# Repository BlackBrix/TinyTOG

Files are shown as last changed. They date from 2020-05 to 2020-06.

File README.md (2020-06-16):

since ATtiny15 MCU is not available anymore, please see the updated project with ATtiny25 in this subfolder here (German):  
[https://github.com/BlackBrix/TinyTOG/tree/master/TinyTOG_NEW_with_ATtiny25#tinytog](https://github.com/BlackBrix/TinyTOG/tree/master/TinyTOG_NEW_with_ATtiny25#tinytog) (German)  
* * *

Oil Sensor Emulation - TinyTOG
==============================

Many Audi type 89, B4 and A4 (B5) enthusiasts want to replace their instrument cluster by a more modern one from an A4 (B5) or A6 (C5). Some just want a more modern design. Others want to equip their car with an orignal Audi radio navigation system, called RNS-D.  
The RNS-D was offered by Audi in two major versions. The first one from about 1997 to 1999 communicates with the instrument cluster via a three-wire-bus the latter one from 2000 to about 2003 uses a CAN bus. So different versions of the RNS-D need different versions of the instrument clusters. Mechanically this makes no difference. From the electronics point of view the CAN bus makes a big difference. But this is another story.  
Along with the CAN bus comes another problem to deal with. These CAN instrument clusters do not have a oil temperature gauge powered by a normal sensor. They communicate with an totally different, intelligent sensor called TOG, made by German manufacturer Hella.  
Retrofitting the TOG is not an option, because Audi invented new oil sumps together with the TOG.  
  
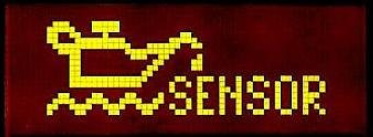
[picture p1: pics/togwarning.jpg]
TOG Warning
  
  
A missing TOG brings up two problems. At first the oil temperature gauge does not work and second the instrument clusters displays a permanent warning message concerning a malfunctioning TOG. This warning cannot be disabled by altering the coding of the instrument clusters. So a different approach had to be taken: TinyTOG.  
  
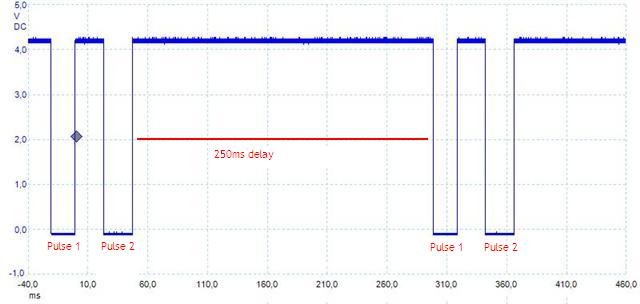
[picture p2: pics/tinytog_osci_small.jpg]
Oscilloscope
  
  
The TOG by Hella uses a simple pulse sequence with the time between two pulses and the length of the pulses representing oil temperature and oil condition/quality. As TinyTOG focuses on engines before 2000 (without long life service) only the coding of the oil temperature was analyzed. It turned out that time between the first and the second pulse together with the length of the second pulse represent the oil temperature. The first pulse is constantly 20ms long. The delay between two cycles must be at least 250ms long.  
  
  Temperature | Time between pulses | Length of pulse 2
  ------------- | ------------- | -------------
41°C | 23.0ms | 24.0ms
60°C | 26.3ms | 27.0ms
65°C | 27.0ms | 27.8ms
70°C | 28.0ms | 28.3ms
75°C | 28.5ms | 29.3ms
80°C | 29.3ms | 30.0ms
85°C | 30.3ms | 30.8ms
90°C | 31.0ms | 31.5ms
95°C | 31.8ms | 32.5ms
100°C | 32.5ms | 33.3ms
105°C | 33.3ms | 34.0ms
110°C | 34.0ms | 35.0ms
115°C | 35.0ms | 35.8ms
120°C | 35.8ms | 36.8ms
125°C | 36.8ms | 37.5ms
130°C | 37.5ms | 38.3ms
135°C | 38.3ms | 39.3ms
140°C | 39.3ms | 40.0ms
145°C | 40.0ms | 40.8ms
150°C | 41.0ms | 41.8ms
155°C | 41.8ms | 42.8ms
160°C | 42.8ms | 43.5ms
165°C | 43.5ms | 44.5ms
170°C | 44.5ms | 45.3ms

In the 1990s almost all Audis equipped with an oil temperature gauge use an oil temperature sensor, part numer 049 919 6563.  
  
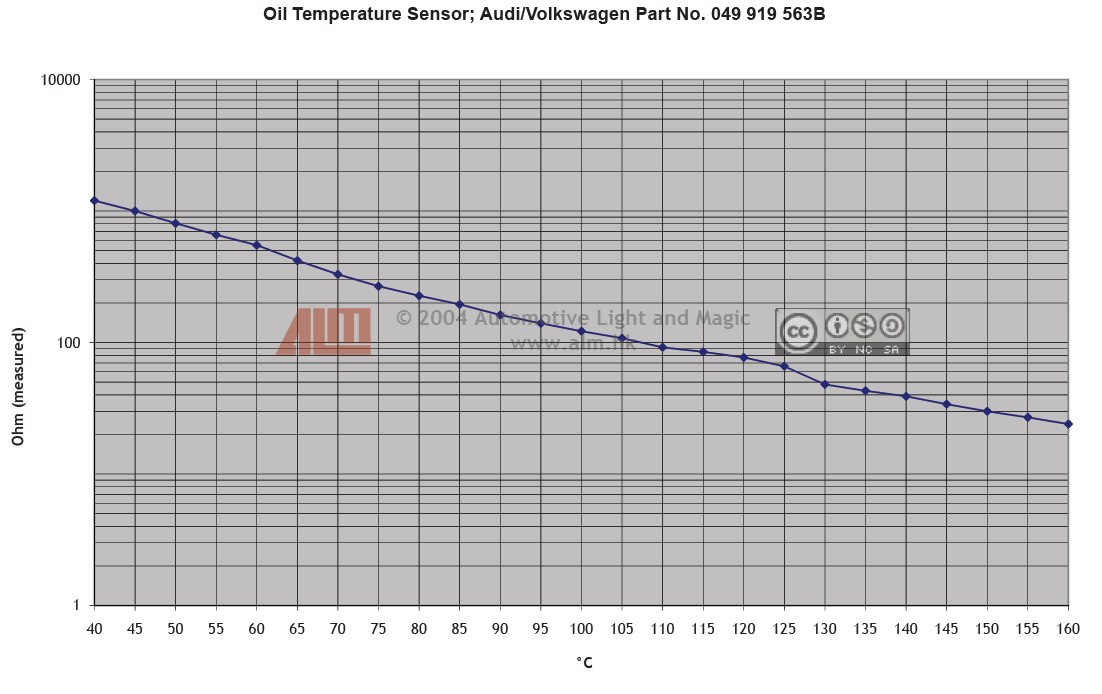
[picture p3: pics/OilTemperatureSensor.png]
Oil Temperature Sensor
  
  
The analog voltage signal from this sensor has to be translated into the above pulse coded signal understood by the instrument cluster. This is done by Atmel's ATTiny15 with its internal 8Bit-ADC. As the oil temperature is a rather imprecise one a stepping of 5K gives enough precision. The gauge's scale begin's at 60°C. So temperature below that don't have to be measured.  
  
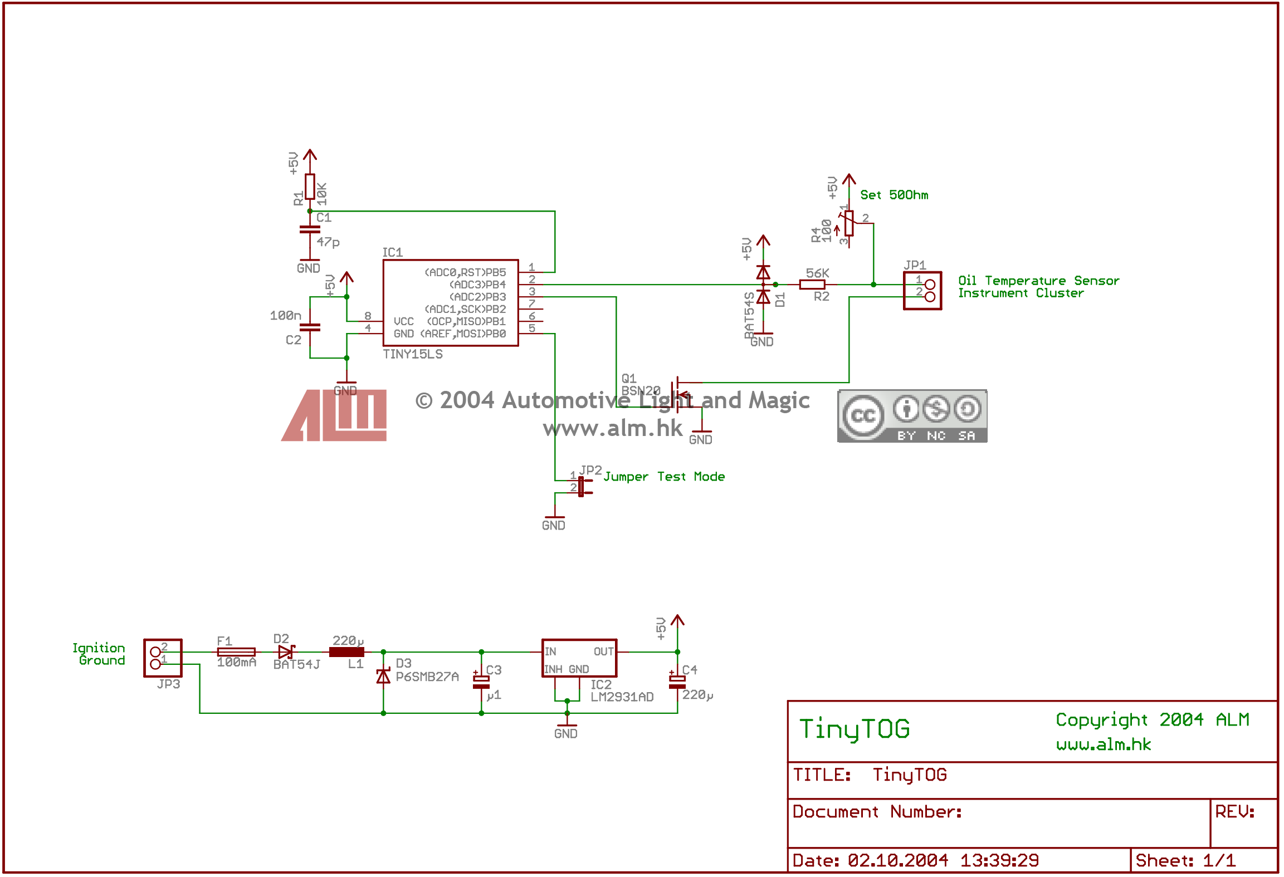
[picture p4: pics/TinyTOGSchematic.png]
TinyTOG Schematic
  
  
TinyTOG needs only be connected to ignition, the instrument cluster and the oil temperature sensor. A jumper is provided to bring up a test mode. Normally this jumper should be left open. By shortening to ground and switching on ignition the fuel gauge should travel from 60°C to full scale and reverse as long as ignition stays high.  
The oil temperature sensor together with an 100Ohm potentiometer form a voltage divider. At first time startup the potentiometer should be tuned to about 50Ohm. Minor adjustments could be made by tuning the potentiometer, but in most cases this is not necessary.  

Downloads
---------

  Content       | License
  ------------- | -------------
  [Schematic and Demo Board](https://github.com/BlackBrix/TinyTOG/tree/master/hardware)  | Creative Commons License (https://creativecommons.org/licenses/by-nc-sa/3.0/hk/)
  [Source code](https://github.com/BlackBrix/TinyTOG/raw/master/firmware/TinyTOG.asm)  | Creative Commons License (https://www.gnu.org/licenses/old-licenses/gpl-2.0.en.html)
  [Intel HEX File](https://github.com/BlackBrix/TinyTOG/raw/master/firmware/TinyTOG.hex)³  |  Creative Commons License (https://www.gnu.org/licenses/old-licenses/gpl-2.0.en.html)
  
³(Internal oscillator calibration set to 0x78)

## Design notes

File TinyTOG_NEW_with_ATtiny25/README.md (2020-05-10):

Audi S4 B5 - Kombiinstrument-Umbau von Vor-Facelift zu Facelift
===============================================================

Der Umbau eines Kombiinstruments (KIs) ist eigentlich keine grosse Sache, wird aber, wenn man ein KI eines anderen Fahrzeugtyps oder eines anderen Modelljahrs des gleichen Fahrzeugstyps umbauen möchte, eventuell wesentlich schwieriger. Einer dieser schwierigen Fälle wird hier beschrieben: Tausch eines KI von einem Audi S4 B5 Modelljahr 1999, nachfolgend als Vor-Facelift bezeichnet, mit einem KI aus einem Audi S4 B5 Modelljahr 2000, nachfolgend als Facelift bezeichnet.

Das KI des Vor-Facelift, nachfolgend als altes KI bezeichnet,

*   mit der Teilenummer 8D0 919 881 L
    
*   ist von VDO,
    
*   hat eine Wegfahrsperre der Generation 2 (WFS 2) und
    
*   eine analoge Uhr.

Das KI des Facelift, nachfolgend als neues KI bezeichnet,

*   mit der Teilenummer 8D0 920 932 JX
    
*   ist ebenfalls von VDO,
    
*   unterstützt CAN-Bus,
    
*   hat ebenfalls eine WFS 2,
    
*   eine digitale Uhr mit Datumsanzeige und
    
*   eine Anschlussmöglichkeit für eine Funkuhr.

Das X am Ende der Teilenummer sagt aus, dass es sich um ein Austauschteil handelt.

Adaption
--------

### Mehrfachstecker

Die Anschlussbuchsen sowie dessen Belegungen unterscheiden sich bei den beiden KIen. Das alte KI hat einen 32-poligen, blauen Anschluss, einen 32-poligen. grünen Anschluss und einen 20-poligen, roten Anschluss. Das neue KI hat ebenfalls den blauen und grünen Anschluss, aber anstelle eines roten Anschlusses einen 32-poligen, grauen Anschluss.

**Übersicht der Belegungen von altem KI zu neuem KI**

Die nachfolgende Tabelle zeigt, wie das neue KI belegt werden muss. Eine Spalte beinhaltet alle Belegungen eines bestimmten Steckers des alten KI und die passende Belegung beim neuen KI. Eine Belegung besteht aus dem Pin und der Farbe des Steckers. In der Spalte auf der linken Seite steht die ursprüngliche Belegung beim alten KI, auf der rechten Seite die passende Belegung bei dem neuen KI.

blauer Stecker | grüner Stecker | roter Stecker
------------- | ------------- | -------------
1 blau → 1 blau | 2 grün → 2 grün | 1 rot → 25 blau 
2 blau → 7 grün | 4 grün → frei | 5 rot → 29 grün 
3 blau → 3 blau | 5 grün → 5 grün | 6 rot → 31 grün 
5 blau → 5 blau | 6 grün → 6 grün | 9 rot → 15 grau 
6 blau → 10 grün | 7 grün → 2 blau | 10 rot → frei 
7 blau → 7 blau | 10 grün → 6 blau | 11 rot → 19 grau 
8 blau → 8 blau | 11 grün → 11 grün | 12 rot → 12 grau 
9 blau → 9 blau | 12 grün → 12 blau | 13 rot → 13 grau 
10 blau → 10 blau | 13 grün → 13 grün | 14 rot → 17 grau 
11 blau → 11 blau | 14 grün → 13 blau | 15 rot → 11 grau 
12 blau → 12 grün | 15 grün → frei | 16 rot → 16 grau 
13 blau → 14 grün | 17 grün → 17 grün | 17 rot → frei 
14 blau → 14 blau | 21 grün → 15 grün | 18 rot → 18 grau 
15 blau → 15 blau | 29 grün → frei | 19 rot → 14 grau 
16 blau → 16 blau | 30 grün → 31 blau |  
17 blau → 17 blau |  |  
18 blau → 18 blau |  |  
19 blau → 21 grün |  |  
20 blau → 20 blau |  |  
21 blau → 21 blau |  |  
22 blau → 22 blau |  |  
23 blau → 23 blau |  |  
24 blau → 24 blau |  |  
25 blau → 28 grün |  |  
26 blau → 26 blau |  |  
27 blau → 27 blau |  |  
28 blau → 28 blau |  |  
29 blau → 29 blau |  |  
30 blau → 30 blau |  |  
31 blau → 27 grün |  |  
32 blau → 32 blau |  |  

*   21 grün vom alten KI ist das Signal des normalen Ölsensors und geht über den TinyTOG zu 15 grün des neuen KIs, um ein TOG-Signal zu emulieren

**Benötigte Teile**

Anz. | Bezeichnung | VAG-Teilenummer
----------| --------- | ---------
1x | Stecker grün | 8L0 972 977 C
1x | Stecker blau | 8L0 972 977 D
1x | Stecker grau | 8L0 972 977 G

Die Kabel habe ich aus ein paar Flachbandkabeln, wie sie bei Computern (IDE-/SCSI\-Kabel) verwendet werden, herausgetrennt.

**Abbildung der Rückseite des neuen KIs**

Bei der Belegung des neuen KIs habe ich keine Änderung an den Steckern am Kabelbaum des Fahrzeugs durchgeführt. Damit ist gewährleistet, dass ich jederzeit ein zu dem Modelljahr passendes KI einbauen kann, um den Originalzustand wiederherzustellen.

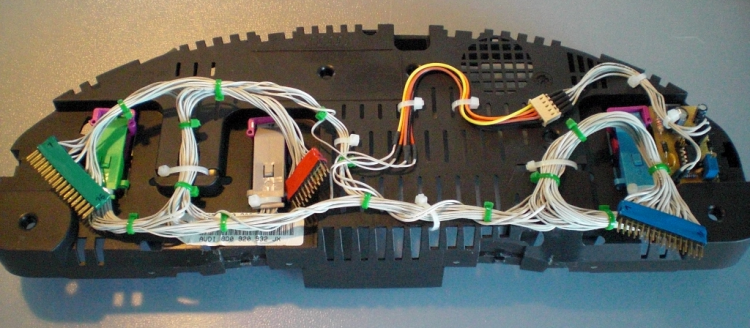
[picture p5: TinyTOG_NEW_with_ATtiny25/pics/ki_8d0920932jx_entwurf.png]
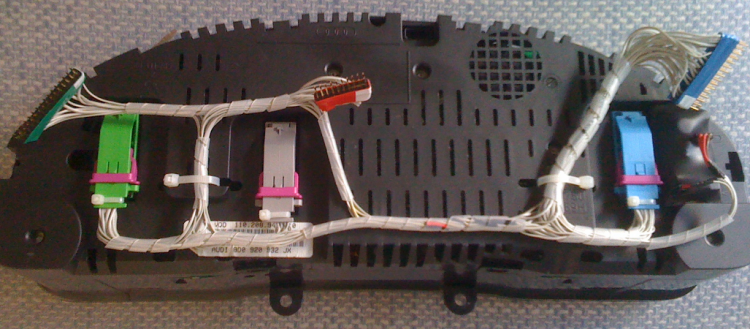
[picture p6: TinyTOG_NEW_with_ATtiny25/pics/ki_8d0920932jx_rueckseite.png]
   

Bei der Belegung ist auf passende Kabellängen zu achten, damit keine Zugbelastungen einzelner Kabel auftreten.

### Temperatur- und Ölstandgeber

Das neue KI hat ein paar mehr Anzeige-Möglichkeiten als das alte KI, sofern entsprechende Sensoren im Fahrzeug verbaut sind, und benötigt einen Temperatur- und Ölstandgeber (TOG), welcher beim Facelift im Zuge der variablen Serviceintervalle (Longlife) eingeführt wurde. Dieser Sensor sitzt beim Facelift auf der Unterseite der Ölwanne, beim Vorface-Lift gibt es diesen Sensor nicht.

Das neue KI wird immer eine Ölstandswarnmeldung anzeigen, wenn es kein plausibles Signal von einem TOG bekommt.



### TinyTOG

Das Signal vom TOG wird mit einer Schaltung, dem TinyTOG von [Automotive Light and Magic (ALM)](http://www.alm.hk/ "http://www.alm.hk"), emuliert. Damit kann der alte Ölsensor (049 919 563 B) weiterverwendet werden und das neue KI zeigt nicht dauerhaft eine Ölstandswarnmeldung an.

Das Herzstück ist ein AVR-Microcontroller, welcher mit dem TinyTOG-Programm die Signale des Ölsensors in TOG-Signale übersetzt. Der Ölsensor gibt die Öltemperatur durch Änderung seines Widerstands an. Der TOG erzeugt wiederkehrend zwei Pulse und eine Pulspause. Die Zeit zwischen den zwei Pulsen und die Länge des zweiten Pulses beschreibt die Öltemperatur.

Der TinyTOG wandelt also den Widerstandswert des Ölsensors in entsprechende Pulse, die ein TOG geben würde, um. Der erste Puls (high = VCC = 5V) ist immer 20 ms lang, die Pause (low = GND = 0V) zwischen erstem und zweiten Puls hat eine Dauer von 23 bis ca. 44 ms, der zweite Puls (high) ist zwischen 24 und 45 ms lang. Das Intervall (low) zwischen den Signalen berägt 250 ms.

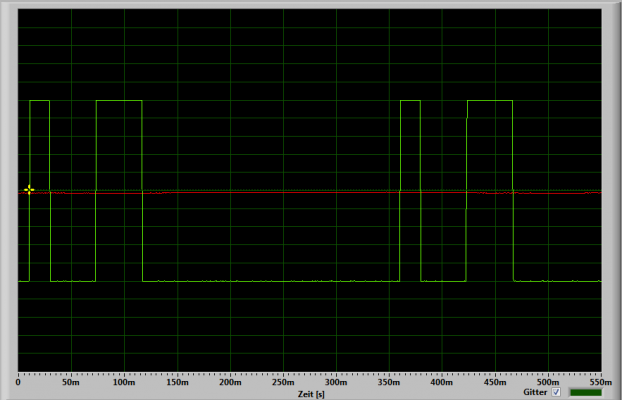
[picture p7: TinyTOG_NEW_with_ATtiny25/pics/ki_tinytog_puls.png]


Folgende Werte ergeben sich für den Ölsensor (049 919 563 B) zur Messung des Widerstandes und damit der Öltemperatur über einen Spannungsteiler mit einem ATtiny25:

*   50 Ohm-Spannungsteiler
    
*   5 V Referenz- und Versorgungsspannung
    
*   10 Bit-Analog-/Digital-Konverter (ADC)
    
Öltemperatur | Ölsensor | U-variabel | ADC | ADCH | 1\. Puls | Pulspause | 2\. Puls
------------ | -------- | ---------- | -------- | -------- | -------- | -------- | -------
**\[°C\]** | **\[Ohm\]** | **\[V\]** | **(10 Bit)** | **(8 Bit)** | **\[ms\]** | **\[ms\]** | **\[ms\]**
41 | 1200 | 4,80 | 983 | 246 | 20,00 | 23,00 | 24,00  
60 | 550 | 4,58 | 939 | 235 | 20,00 | 26,25 | 27,00  
65 | 420 | 4,47 | 915 | 229 | 20,00 | 27,00 | 27,75  
70 | 330 | 4,34 | 889 | 222 | 20,00 | 28,00 | 28,25  
75 | 268 | 4,21 | 863 | 216 | 20,00 | 28,50 | 29,25  
80 | 227 | 4,10 | 839 | 210 | 20,00 | 29,25 | 30,00  
85 | 195 | 3,98 | 815 | 204 | 20,00 | 30,25 | 30,75  
90 | 162 | 3,82 | 782 | 196 | 20,00 | 31,00 | 31,50  
95 | 140 | 3,68 | 755 | 189 | 20,00 | 31,75 | 32,50  
100 | 122 | 3,55 | 726 | 182 | 20,00 | 32,50 | 33,25 
105 | 108 | 3,42 | 700 | 175 | 20,00 | 33,25 | 34,00 
110 | 92 | 3,24 | 663 | 166 | 20,00 | 34,00 | 35,00  
115 | 85 | 3,15 | 645 | 161 | 20,00 | 35,00 | 35,75  
120 | 77 | 3,03 | 621 | 155 | 20,00 | 35,75 | 36,75  
125 | 66 | 2,84 | 583 | 146 | 20,00 | 36,75 | 37,50  
130 | 48 | 2,45 | 502 | 125 | 20,00 | 37,50 | 38,25  
135 | 43 | 2,31 | 473 | 118 | 20,00 | 38,25 | 39,25  
140 | 39 | 2,19 | 449 | 112 | 20,00 | 39,25 | 40,00  
145 | 34 | 2,02 | 414 | 104 | 20,00 | 40,00 | 40,75  
150 | 30 | 1,88 | 384 | 96 | 20,00 | 41,00 | 41,75 
155 | 27 | 1,75 | 359 | 90 | 20,00 | 41,75 | 42,75  
160 | 24 | 1,62 | 332 | 83 | 20,00 | 42,75 | 43,50  
170 | 23 | 1,58 | 323 | 81 | 20,00 | 44,50 | 45,25

Die Schaltung für den TinyTOG kann ohne Probleme auf einer Lochraster-Platine aufgebaut werden.

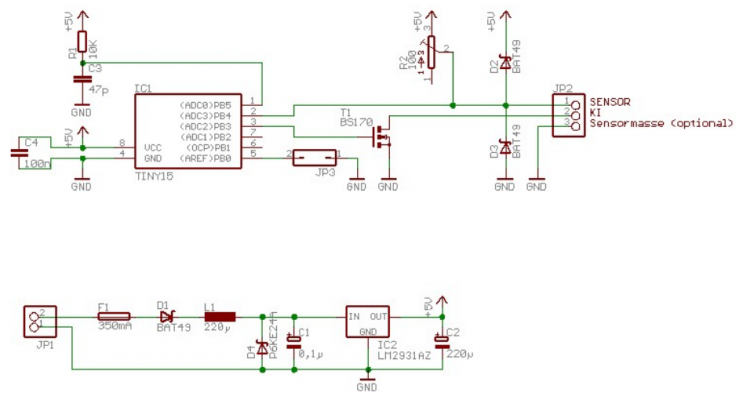
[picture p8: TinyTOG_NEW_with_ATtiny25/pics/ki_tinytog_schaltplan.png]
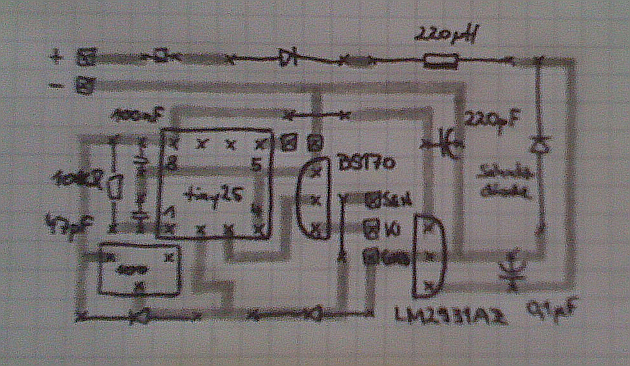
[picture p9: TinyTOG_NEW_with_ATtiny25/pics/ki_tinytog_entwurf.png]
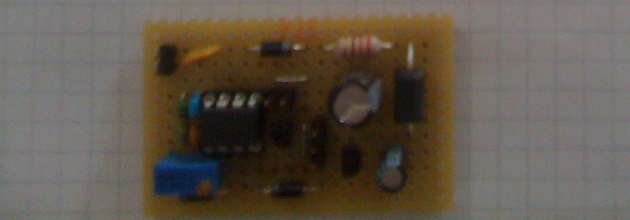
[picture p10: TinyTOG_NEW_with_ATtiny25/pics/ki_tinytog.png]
  

**Benötigte Teile**

Abk. | Anz. | Bezeichnung | Reichelt-Best.-Nr.
-------- | -------- | -------- | --------
JP1-3 | 1x  | 36-pol. Stiftleiste gerade 2,54mm | SL 1X36G 2,54
 .    | 1x | Lochrasterplatine | H25PR200
C1 | 1x | Elektrolyt 0,1µF 100V | RAD 0,1/100  
C2 | 1x | Elektrolyt 220µF 16V | RAD 220/16  
D1 | 1x | Schottky 30V 1A | SB 130  
D4 | 1x | Übersp.-Schutz-Diode | 1,5KE 24A  
F1 | 1x | Rück. Sicherung 40A 60V 3,8s | PFRA 040  
IC2 | 1x | Spannungsregler 5V | LM 2931 AZ  
L1 | 1x | Drosselspule 220µH | SMCC 220µ  
C3 | 1x | Keramik 47pF 50VDC | KERKO 47P  
C4 | 1x | Keramik 100nF 50VDC | KERKO 100N  
D2, D3 | 2x | Schottky 30V 1A | SB 130  
R1 | 1x | Metallschicht 2W 10kOhm | 2W METALL 10K  
R2 | 1x | Präzisionspoti 100Ohm | 64Y-100  
T1 | 1x | N-FET 60V 500mA | BS 170  
IC1 | 1x | Atmel AVR Tiny 25 | ATTINY 25-20 PU  
.   | 1x | IC-Sockel 8-polig | GS 8P  

Das ursprüngliche Programm für den TinyTOG ist von ALM in Assembler geschrieben worden. Die Schaltung ist von 2004 und sieht einen Atmel AVR Tiny 15 (tiny15) als Microcontroller vor, welcher aber nicht mehr hergestellt wird. Als Ersatz bietet sich ein Atmel AVR Tiny 25 (tiny25) an.

Der tiny25 kann in einen tiny15-Kompatibilitätsmodus versetzt werden, welcher den tiny25 quasi zu einem tiny15 umwandelt. Dennoch waren kleine Änderungen an dem originalen TinyTOG-Programm für den Einsatz auf einem tiny25 erforderlich.

*   das ADC Control and Status Register (ADCSR) wude von „ADCSR“ in „ADCSRA“ umbenannt
    
*   die Werte für den 10 Bit-ADC (siehe Tabelle oben) wurden angepasst

Das Programm muss auf den tiny25 übertragen werden. Für diesen Zweck kann z. B. WinAVR, welches avrdude beinhaltet, und ein einfacher IC-Programmieradapter (z. B. [SI-Prog](http://www.whoopsie.de/home/doku.php?id=topic02:item004 "topic02:item004")) verwendet werden

Nachfolgend eine Batch-Datei zum Schreiben des tiny25 mit avrdude von WinAVR mit einem SI-Prog.
~~~
@echo off
set port=com1
set prog=siprog
set mmcu=attiny25
set hexfile=TinyTOG
rem # ATtiny25-Fuses
rem 0x62 = Clock: intern 8 MHz, Prescale: 8 (default)
rem 0xE2 = Clock: intern 8 Mhz, kein Prescale
rem 0x63 = Clock: intern 1,6 MHz (tiny15)
set lfuse=0x63
avrdude.exe -p %mmcu% -P %port% -c %prog% -U lfuse:w:%lfuse%:m -U flash:w:%hexfile%.hex:a
~~~

Es können natürlich auch andere Programme (z. B. PonyProg) zum Flashen verwendet werden.

Das TinyTOG-Programm hat ein Demoprogramm integriert, um die Funktion der Schaltung zu überprüfen. Zur Aktivierung des Testprogramms werden die beiden Pins direkt neben dem Microcontroller mittels Jumper verbunden. Bei aktiviertem Testprogramm werden nacheinander Öltemperaturen in 5°C-Schritten simuliert. Beginnend bei 170°C wird ungefähr alle 80 s die simulierte Öltemperatur um 5°C geringer, bis 60°C und im nächsten Schritt 41°C erreicht sind.

Ein 100 Ohm-Präzisionspoti dient zur Feinjustierung. Da in der kleinen Öltemperaturanzeige im KI ohnehin nur eine ungefähre Anzeige möglich ist, sollte ein Wert von 50 Ohm in den meisten Fällen ausreichend genau sein.

Die Spannungsversorgung sollte über Klemme 15 (Zündungsplus) und Klemme 31 (Lastmasse) erfolgen. Beim alten und neuen KI liegt

*   Klemme 15 auf 1 blau und
    
*   Klemme 31 z. B. auf 9 blau.

Wegfahrsperre
-------------

Eine WFS ist ein verbundenes Sicherheitssystem im Fahrzeug, welche das unerlaubte Starten des Motors verhindern soll und erstreckt sich über

*   das Motorsteuergerät,
    
*   das Kombinstrument oder einer seperaten, eigenen Einheit und
    
*   den Schlüsseln.

Es ist grundsätzlich möglich ein KI mit WFS 2 oder WFS 3 in ein Fahrzeug mit WFS 2 zu verbauen. Ein KI mit WFS 2 hat nur seine 14-stellige ID gespeichert. Bei WFS 3 werden zusätzlich die 17-stellige Fahrgestellnummer, welche ebenfalls im Motorsteuergerät gespeichert ist, und Informationen zum Hersteller, Fahrzeugtyp, Modelljahr und das Herstellwerk gespeichert. Die WFS 2 wurde beim Audi S4 B5 von 1997 bis ca. 2001 verbaut.

Das neue KI muss nach dem Einbau

*   an das Motorsteuergerät angeglichen werden und
    
*   die zum Starten berechtigten Schlüssel angelernt bekommen.

Das Anlernen und Angleichen kann z. B. mit VCDS durchgeführt werden.

### Schlüssel anlernen

Voraussetzung: Das neue KI ist eingebaut und der Login-Code für das neue KI ist bekannt.

In meinem Fall hatte ich nicht den Login-Code zu dem neuen KI. Es gibt aber günstige Programme wie z. B. VAGTacho, welche über einen eigenen OBD-Stecker den Login eines KIs bis ca. Baujahr 2002 auslesen können. Ich selber habe das Programm auch genutzt, allerdings funktionierte es nur bei dem alten KI, nicht aber bei dem neuen KI. Es half nur das direkte Auslesen des EEPROMs.

Steuergerät: Schalttafeleinsatz / Kombiinstrument

*   \[Login - 11\] → fünfstelligen Login-Code des neuen KIs eingeben (z. B. für Login-Code 1234 = 01234)
    
*   \[Anpassung - 10\] → Anpassungskanal 21 auslesen
    
    *   Der gespeicherte und angezeigte Wert ist die Anzahl der alten, angelernten Schlüssel. Der Wert wird auf 0 gesetzt und gespeichert, damit die alte Schlüsselzuordnung gelöscht wird. Anschliessend wird die neue Anzahl der anzulernenden Schlüssel eingegeben und gespeichert. Nach der Speicherung ist der erste Schlüssel angelernt und die Kontrollleuchte der Wegfahrsperre im KI sollte erlischen.
        
    *   Ein neuer, anzulernender Schlüssel wird in das Zündschloss gesteckt und die Zündung einschaltet. Die Kontrollfeuchte der Wegfahrsperre schaltet sich für ca. 2 Sekunden ein und erlischt dann wieder. Der Schlüssel ist angelernt. Der Vorgang wird für alle anzulernenden Schlüssel wiederholt.

### Motorsteuergerät angleichen

Steuergerät: Schalttafeleinsatz / Kombiinstrument

*   \[Login - 11\] → fünfstelligen Login-Code des neuen KIs eingeben (z. B. für Login-Code 1234 = 01234)
    
*   \[Anpassung - 10\] → Anpassungskanal 0 auslesen und speichern, um das Motorsteuergerät mit dem KI bekannt zu machen

Login-Code und Laufleistung
---------------------------

Der 93lc86 ist ein serieller Microwire-EEPROM mit 2 kByte Speicher. Dieser EEPROM wird bei dem neuen KI zur Speicherung von u. a. Login-Code und Laufleistung genutzt, welche je nach Baujahr, Hersteller und WFS-Generation dort in irgendeiner Form abgelegt sind.

Um auf den EEPROM zugreifen zu können muss das KI geöffnet werden und mit einem IC-Programmieradapter, z. B. dem [SI-Prog](http://www.whoopsie.de/home/doku.php?id=topic02:item004 "topic02:item004") verbunden werden. Mit einem passenden Programm, z. B. PonyProg, kann dann der Inhalt des EEPROMs, der Dump, ausgelesen werden.

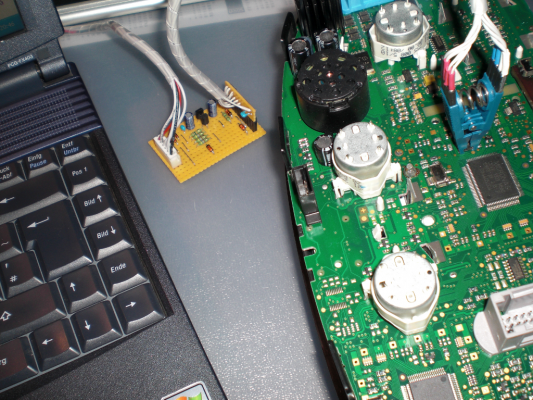
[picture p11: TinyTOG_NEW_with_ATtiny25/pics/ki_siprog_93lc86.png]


Der Dump kann als Datei gespeichert und anschließend mit einem Hex-Editor geöffnet werden. Im Hex-Editor werden 16 Bit üblicherweise hexadezimal mit vier Zeichen (jeweils von 0 bis 9, dann A bis F für dezimal 0 bis 15) angezeigt.

Der Dump ist korrekt, wenn man irgendwo im Hex-Editor eine 14-stellge WFS-ID und die Teilenummer des KIs erahnen kann.

Es gibt Programme, z. B. IMMOread by Gsmservis, welche Login-Codes aus solchen Dumps auslesen können. Für meinen Dump hat das Programm allerdings nicht funktioniert.

### Login-Code auslesen

Der Login-Code steht an der Stelle 0x7E2 dreimal hintereinander in 16 Bit Länge.



Die hexadezimale Darstellung muss lediglich in eine dezimale Darstellung gebracht werden.

*   0x000_2_ = 2 \* 16^0 = 2 \* 1 = 2
    
*   0x00_D_0 = 13 \* 16^1 = 13 \* 16 = 208
    
*   0x0_4_00 = 4 \* 16^2 = 4 \* 256 = 1024
    
*   0x_0_000 = 0 \* 16^3 = 0 \* 4096 = 0

Die dezimale Darstellung von 0x04D2 und damit der Login-Code ist 0 + 1024 + 208 + 2 = 1234.

Der Login-Code hat fast immer einen 4-stelligen Wert, muss aber in VCDS 5-stellig, hier also mit führender Null, eingegeben werden.

### Laufleistung ändern

Mit VCDS ist aus Sicherheitsgründen nur eine Anpassung eines km-Stands von unter 100 km möglich. Ein gebrauchtes KI, welches typischerweise aus einem anderen Fahrzeug ausgebaut wurde, hat in den allermeisten Fällen einen höheren km-Stand gespeichert. Eine Anpassung des km-Stands mit VCDS ist dann nicht möglich.

**Berechnung der Laufleistung**

Die Laufleistung wird hier exemplarisch ermittelt und beträgt 311.177 km. Sie wird an der Stelle 0x42 in 8 mal 16 Bit Länge im EEPROM gehalten.



Zuerst werden die beiden 16 Bit-Pakete in ihre dezimale Darstellung überführt, wobei 0xB403 fünfmal und 0xB404 dreimal vorkommt. Der Einfachheit halber braucht nur ein 16 Bit-Paket überführt werden, da das jeweils andere Paket entweder einen um den Wert 1 höheren oder niedrigeren Wert hat.

*   0x000_3_ = 3 \* 16^0 = 3 \* 1 = 3
    
*   0x00_0_0 = 0 \* 16^1 = 0 \* 16 = 0
    
*   0x0_4_00 = 4 \* 16^2 = 4 \* 256 = 1.024
    
*   0x_B_000 = 11 \* 16^3 = 11 \* 4096 = 45.056

Die hexadezimalen Werte 0xB403 bzw. 0xB404 entsprechen den dezimalen Werten 45.056 + 1.024 + 0 + 3 = 46.083 bzw. 46.083 + 1 = 46.084.

Definierte Werte:

*   a1 := dezimaler Wert des ersten 16 Bit-Pakets
    
*   a2 := dezimaler Wert des zweiten 16 Bit-Pakets
    
*   n1 := Anzahl des ersten 16 Bit-Pakets
    
*   n2 := Anzahl des zweiten 16 Bit-Pakets
    
*   x = 49
    
*   y = (n1+n2) \* 65.535 = 8 \* 65.535 = 524.280

Rechenschema:

*   a1 = 46.083
    
*   a2 = 46.084

*   b1 = n1 \* a1 = 5 \* 46.083 = 230.415
    
*   b2 = n2 \* a2 = 3 \* 46.084 = 138.252

*   b = b1 + b2 = 368.667
    
*   c = y - b = 155.613
    
*   d = c \* 2 = 311.226
    
*   e = d - 49 = 311.177

Der Wert e entspricht der Laufleistung in km.

**Anpassung der Laufleistung**

Die Änderung erfolgt im Dump, also in dem EEPROM-Abbild, welcher nach der Änderung zurück in den EEPROM geschrieben wird.

Exemplarisch wird hier die Laufleistung auf 261.039 km geändert. Dazu muss die Laufleistung wie o. a. nur in umgekehrter Reihenfolge in die hexadezimale Darstellung überführt werden.

Definierte Werte:

*   e := Wert der Laufleistung in Kilometer
    
*   n := Anzahl der darzustellenden 16 Bit-Pakete
    
*   x = 49
    
*   y = n \* 65.535 = 8 \* 65.535 = 524.280

Rechenschema:

*   e = 261.039
    
*   d = e + x = 261.088
    
*   c = d / 2 = 130.544
    
*   b = y - c = 393.736

Überführung in acht 16 Bit-Pakete:

*   a = b / n = 393.736 / 8 = 49.217

Umformung von dezimaler in hexadezimale Darstellung:

*   49.217 / 16 = 3.076 , Rest 1
    
*   3.076 / 16 = 192 , Rest 4
    
*   192 / 16 = 12 , Rest 0
    
*   12 / 16 = 0 , Rest 12 = C

Der dezimale Wert 49.217 entspricht dem hexadezimalen Wert 0xC041.

In diesem Dump wurde der Wert 0xC041 in Big-Endian gespeichert, d. h. erst C0 und dann 41. In Little-Endian werden zuerst die niederwertigsten Bits gespeichert, dort wäre zuerst 41 und dann C0 gespeichert.



Downloads
---------

*   [Firmware](https://github.com/BlackBrix/TinyTOG/tree/master/TinyTOG_NEW_with_ATtiny25/firmware)

Quellen
-------

*   [http://www.alm.hk/tiny/tinytog.php](http://www.alm.hk/tiny/tinytog.php "http://www.alm.hk/tiny/tinytog.php") - Automotive Light and Magic / Oil Sensor Emulation
    
*   [http://www.gti-tdi.de/board2/index.php](http://www.gti-tdi.de/board2/index.php "http://www.gti-tdi.de/board2/index.php") - Dashboard Forum
    
*   [http://www.motor-talk.de/blogs/spatwitz/umbau-auf-tt-tacho-t2587381.html](http://www.motor-talk.de/blogs/spatwitz/umbau-auf-tt-tacho-t2587381.html "http://www.motor-talk.de/blogs/spatwitz/umbau-auf-tt-tacho-t2587381.html") - Umbau TT-Tacho in Golf III
    
*   [http://www.michaelneuhaus.de/forum/viewtopic.php?f=6&t=2630#p15707](http://www.michaelneuhaus.de/forum/viewtopic.php?f=6&t=2630#p15707 "http://www.michaelneuhaus.de/forum/viewtopic.php?f=6&t=2630#p15707") - TT-Tacho Umbau in Golf III/IV
    
*   [www.lutschi.biz/navi/Audi/umbau\_kombiinstrument.pdf](http://www.lutschi.biz/navi/Audi/umbau_kombiinstrument.pdf "http://www.lutschi.biz/navi/Audi/umbau_kombiinstrument.pdf") - Umbau KI A6 C5 2.5 TDI von 3-Leiter-Bus auf CAN-Bus

Links
-----

*   [http://www.lancos.com/prog.html](http://www.lancos.com/prog.html "http://www.lancos.com/prog.html") - PonyProg
    
*   [http://winavr.sourceforge.net/](http://winavr.sourceforge.net/ "http://winavr.sourceforge.net/") - WinAVR
    
*   [http://www.zeitnitz.de/Christian/scope\_de](http://www.zeitnitz.de/Christian/scope_de "http://www.zeitnitz.de/Christian/scope_de") - Soundcard Scope

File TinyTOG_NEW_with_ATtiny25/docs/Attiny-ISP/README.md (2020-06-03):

you can buy one here:  
https://www.tindie.com/products/rullywow/attiny85-isp-breakout-kit-includes-attiny85-20pu  
or here:  
https://rullywow.com/product/attiny85-isp-arduino-compatible-wattiny85-microcontroller

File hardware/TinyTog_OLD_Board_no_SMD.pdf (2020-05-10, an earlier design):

TinyTog
In diversen Foren finden sich Umbauanleitungen für den Umbau von A4, A6 und auch 80er auf neuere Kombiinstrumente, meistens vor dem Hintergrund, daß ein Navi-Plus implantiert werden soll und man latürnich nicht auf die Darstellung im Kombiinstrument verzichten will.
Eine große Hürde dabei ist der sog. TOG (Temperatur- und Ölstandgeber). Dieser Geber ist bei allen neueren Audis mit variablen Service-Intervallen verbaut und sitzt in der Ölwanne. Das Fehlen dieses Gebers wird vom KI mit einer Fehlermeldung im FIS quittiert, die sich nicht abschalten/unterdrücken läßt. Konsequenz der meisten im Netz beschriebenen Umbauanleitungen fürs KI ist dann eine der folgenden Lösungen beschrieben:
1. Eine neue Ölwanne mitsamt TOG einbauen. Aber wozu eine (allein schon die Teile >150EUR) Umrüstung der Ölwanne bei einem Motor, der ohnehin nicht für variable Intervalle freigegeben ist und dann im KI die Anpassungskanäle so setzen, daß wieder ein festes Intervall gesetzt ist? oder
2. Den TOG kaufen und in eine Dose mit Öl zu legen. Einfach nur Anschließen bringt nichts, da dann alle 100km eine Warnung wg. zu geringen Ölstands kommt. Da baut man sich ein neues KI mit FIS und damit auch mit einer Öltemp.anzeige ein, aber die Öltemp.anzeige zeigt nichts an.

Da ich selber ein KI in ein Auto einbaue, für das es gar keine Wanne mit TOG gibt und aber auch nicht auf die Öltemp. verzichten wollte, ist TinyTog entstanden.

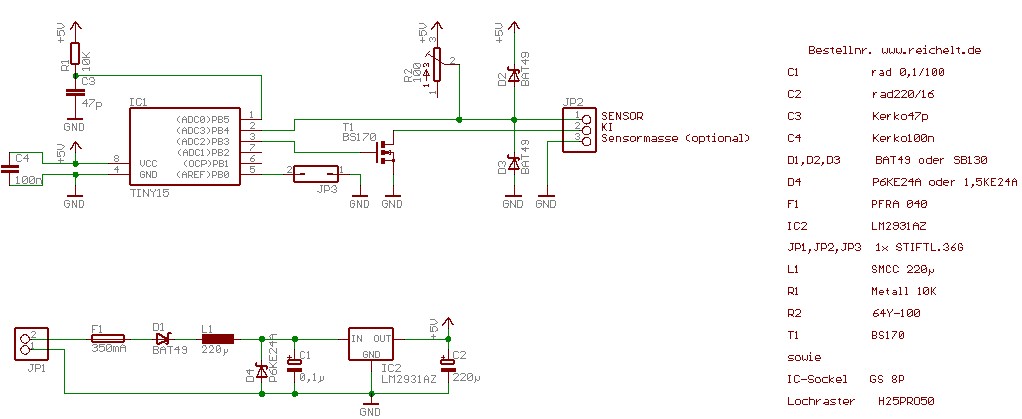
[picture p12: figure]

Es wandelt das Signal des normalen Öltemp.gebers in ein TOG-Signal und gaukelt damit dem KI einen TOG vor. Netter Nebeneffekt: man hat (wieder) eine funktionierende Öltemp.anzeige. Selbst wenn der Geber (bei allen Audis seit Jahrzehnten derselbe) noch nicht vorhanden ist, kann er bei allen Autos, die es mit FIS oder zumindest mit Zusatzinstrumenten gab, immer nachgerüstet werden. Die Bohrung an der Ölwanne oder am Flansch des Ölfilters ist immer da, nur steckt halt eine Schraube drin. Erschreckend ist die Einfachheit der Schaltung. Ein kleiner Microcontroller mit AD-Wandler liest die Werte des Öltemp.gebers und wandelt sie in das TOG-Signal. Die Spannungsversorgung des MCs benötigt mehr Platz als die

eigentliche Schaltung.
Den Anschluß Sensormasse kann man auch weglassen. Zwar hat der Geber eigentlich seine Masse übers Gewinde. Eine extra Leitung zur Schaltung kann aber nochmals einen besseren Schutz gegen Über-/Unterspannung bieten. Wie man in de Schaltung sieht, hängt der Geber (der Einfachheit halber) an 5V und nicht an 12V. Die Masse-Leitung muß nicht sein, aber für Vorsichtige nicht verkehrt. Das Gehäuse des Gebers läßt sich leicht löten.

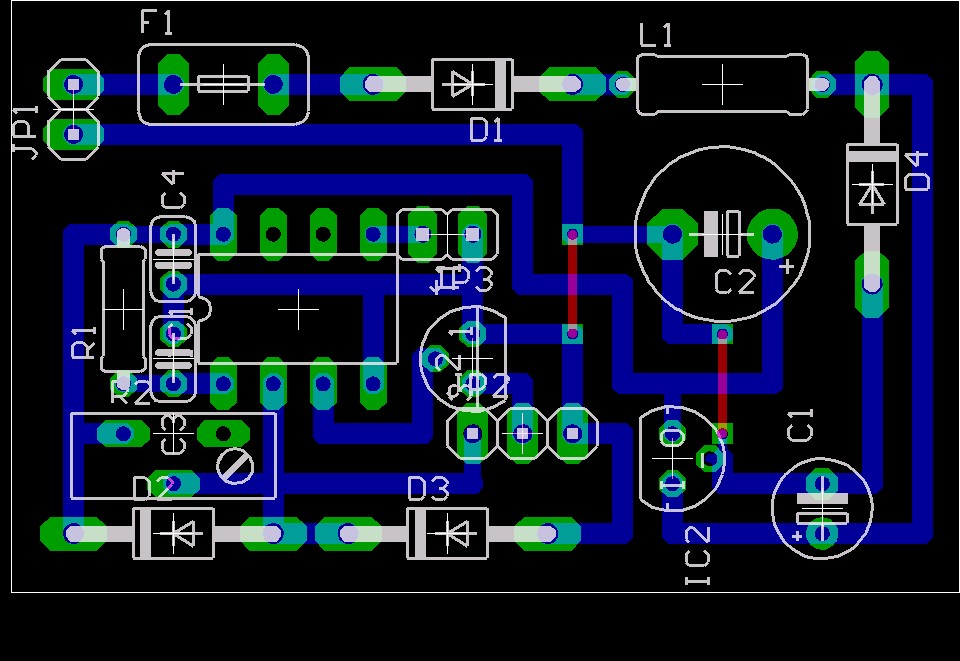
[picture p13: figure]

Die Experimente zur Schaltung haben einige interessante Punkte zur originalen Anzeige hervorgebracht. Die Anzeige im KI geht bis 180Grad. Auch wenn beim Outputtest (mit VAG-Com) die Nadel der Öltemp.anzeige bis zum Vollausschlag 180Grad geht, wird wohl kein Audi-Fahrer diese je zu sehen bekommen. Abgesehen davon, daß bei solchen Öltemperaturen wohl ehe schon alles zu spät wäre, geht die Anzeige nur bis ca. 173Grad. Werte darüber zeigt das KI als 173Grad an. Der Meßwertblock im KI hört sogar schon bei 155Grad auf. Bei allen KIs, die ich für die Tests hatte, zeigte (unter Berücksichtigung des Parallaxenfehlers) die Anzeige immer ein wenig mehr an als im Meßwertblock stand, aber bei 173 Grad war immer das Ende erreicht. Da die Skala der Öltemp.anzeige erst bei 60Grad anfängt, wird bei Öltemperaturen darunter einfach 40Grad ans KI übermittelt Ab 60Grad geht's dann in 5Grad Schritten weiter bis 173Grad. Eine höhere Genauigkeit wäre angesichts der Anzeige völlig überflüssig. Es braucht auch niemand Angst haben, daß evt. die Anzeige im KI ständig zwischen zwei Werten (mit 5Grad Unterschied) pendelt. Erstens ist die Anzeige sehr träge und zweitens mittelt das KI die eingehenden Werte. Wenn man dem KI z.B. abwechselnd 60Grad und 140Grad schickt, zeigt es 100Grad an.

Für Genauigkeitsfreaks gibt's aber einen Spindeltrimmer, mit dem man einen evt. Offset-Fehler des Wandlers ausgleichen kann. Ansonsten ist ein Testprogramm integriert, mit dessen Hilfe man schauen kann, ob das eigene KI mit TinyTog richtig zusammenarbeitet. Mittels eines Jumpers kann beim Einschalten der Zündung ein Testprogramm gestartet werden. Die Anzeige geht dann sofort auf 173Grad und geht dann ca. alle 80s um 5Grad runter bis 60Grad und dann auf 40Grad. Danach wiederholt sich das Ganze von vorne bis zum Ausschalten der Zündung. Warum so langsam? Latürnich kann man im Meßwertblock nachschauen, ob auch alle gelieferten Werte vom KI richtig gelesen werden können. Aber wenn man kein VAGCOM hat, dann hilft eben nur Ausprobieren. Wenn der TOG bzw. TinyTog nicht mehr richtig arbeitet oder unplausible Werte liefert, dann meckert das KI erst nach 60s, legt einen Fehler im Fehlerspeicher ab und die Anzeige geht auf unter 60Grad. Sobald wieder ein korrektes Signal kommt, wird wieder etwas angezeigt. Mittels des Testprogramms kann man also in einer halben Stunde alle Werte durchtesten und schauen, ob das KI auch brav das Richtige anzeigt und eben nicht meckert.
Bevor jetzt jemand fragt. Ich will kein Geld damit verdienen. Das ist Spaß an der Freude. Wenn jemand die Schaltung haben will, dann kann er sich die gerne nach der Abbildung hier selber löten.
Kosten: Der Öltemp.geber kostet keine 15EUR und die Bauteile für die Schaltung weniger als 15EUR.
Den Aufbau des Spannungsreglers kann man auch gerne variieren, wenn man weiß, was man tut. Meiner ist dimensioniert für Teile, die ich an einem Sonntag-Nachmittag so in meiner Hausapotheke gefunden habe. Der Nachbau dürfe auf Lochraster auch für weniger Geübte kein Problem sein. Die Schaltung paßt in eine Streichholzschachtel und benötigt außer Kl.31, Kl.15, dem Signal vom Geber und der Leitung zum KI keine weiteren Anschlüsse.
Den programmierten MC kann man von mir bekommen. Näheres dazu im Nachtrag am Ende Einfach eine PN an Axel in Meckis Forum (www.meckisforum.de) schicken.
Der originale TOG kann übrigens sehr schön zwischen Motoröl und z.B. Oliven- oder Sonnenblumenöl unterscheiden. Vom Prinzip her funktioniert er wohl wie ein Luftmassenmesser. Wenn ich Zeit habe und mir Uwe seinen Sensor noch mal schickt, könnte man schauen, ob er auch neues von ranzigem Friteusenfett unterscheidet. Ungeahnte Anwendungsmöglichkeiten ließen sich dann aufzeigen....
Womit ich auch bei den Danksagungen angekommen wäre: Danke an Uwe Reil und seine Frau. Uwe hat seinen TOG aus der Dose im Motorraum zur Verfügung gestellt. Uwes Frau hat die Friteuse für das Ausmessen des herkömmlichen Gebers zur Verfügung gestellt. Wobei ich nicht genau weiß, ob sie das auch weiß. Sie war wohl an dem Tag als Uwe die Kennlinie gemessen hat nicht da... Uwe ist auch (wiedermal) das Testkanninchen für den Einbau in einen A4. Ich selbst habe einen A3 mit TinyTog ausgestattet. Beide Autos laufen problemlos.

Hier noch zwei Bilder von Uwes Einbau:

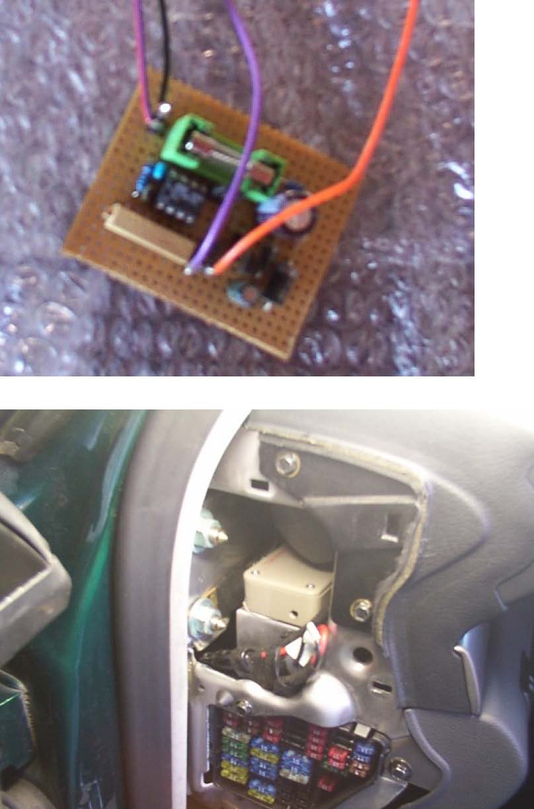
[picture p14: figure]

Viel Spaß beim Nachbau

Axel

Nachtrag:

Inzwischen habe ich rund 30 programmierte MC verschickt. Wie heutzutage üblich, hört man meistens nur was von den Leuten, wenn etwas schief gegangen ist. Mir ist jedoch noch kein Fall zu Ohren gekommen in dem die Schaltung versagt hätte. Es waren immer Fehler beim Löten.

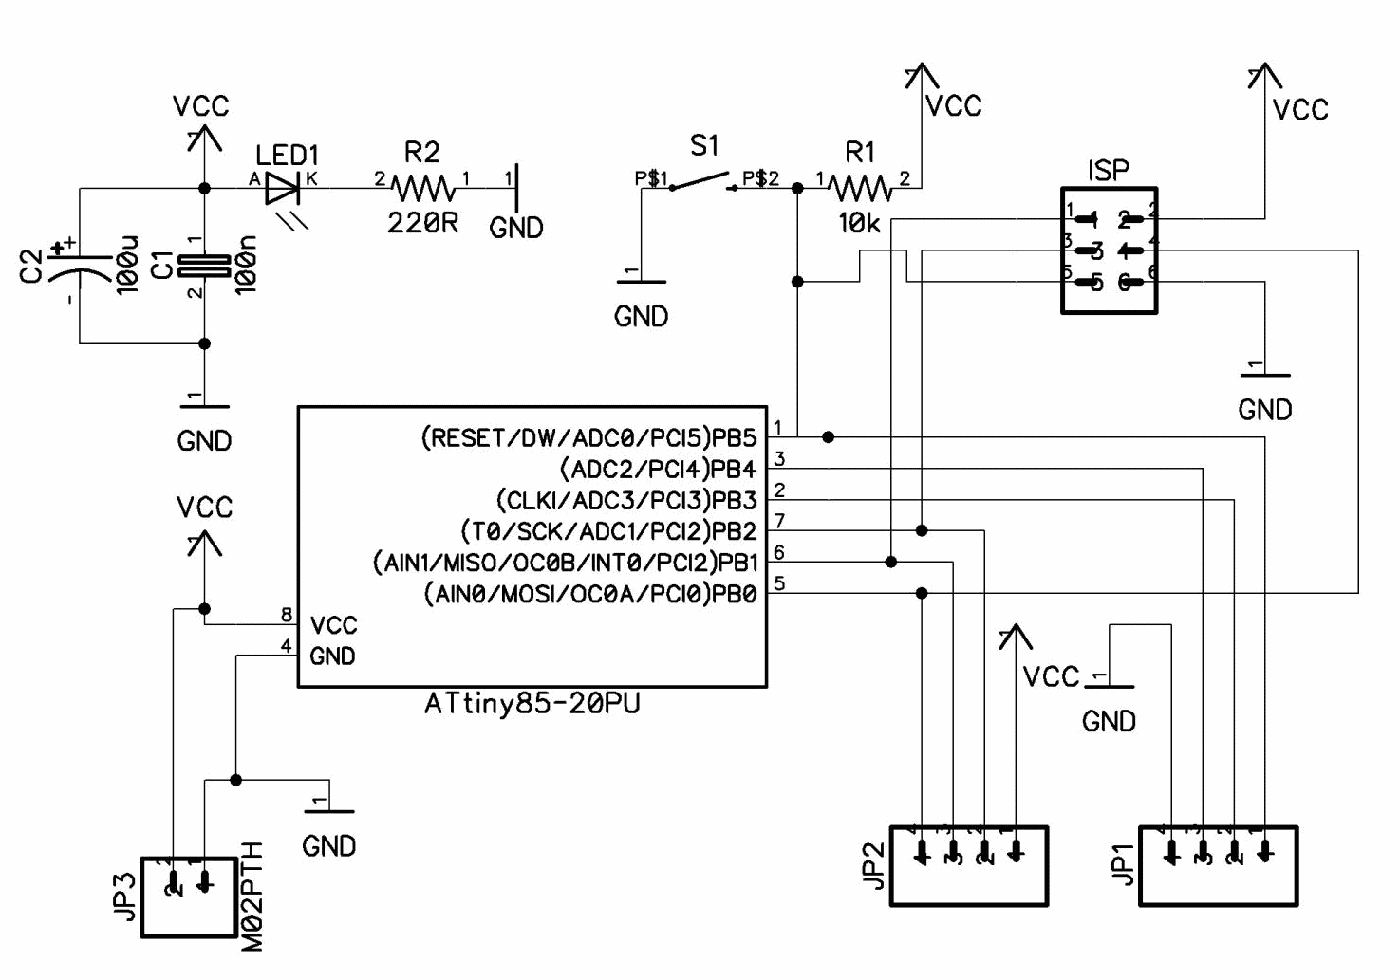
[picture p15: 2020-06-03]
TinyTOG_NEW_with_ATtiny25/docs/Attiny-ISP/Attiny-ISP_schematic.png

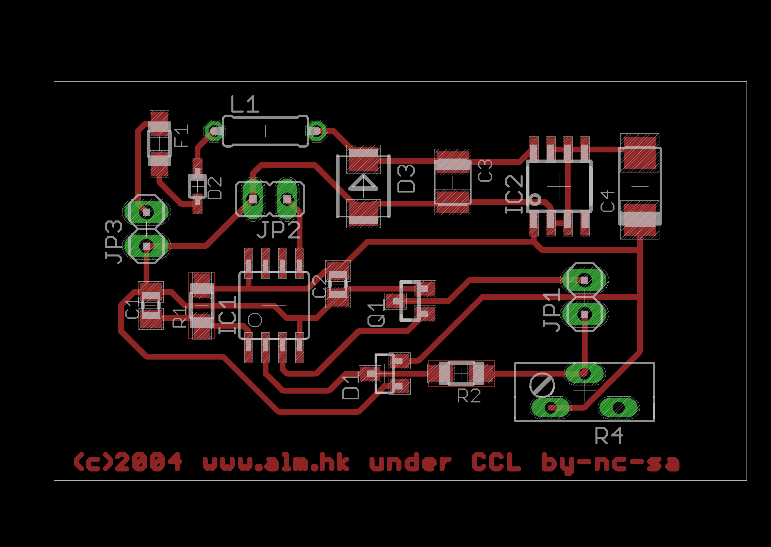
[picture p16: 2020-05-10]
hardware/TinyTOGBoard.png

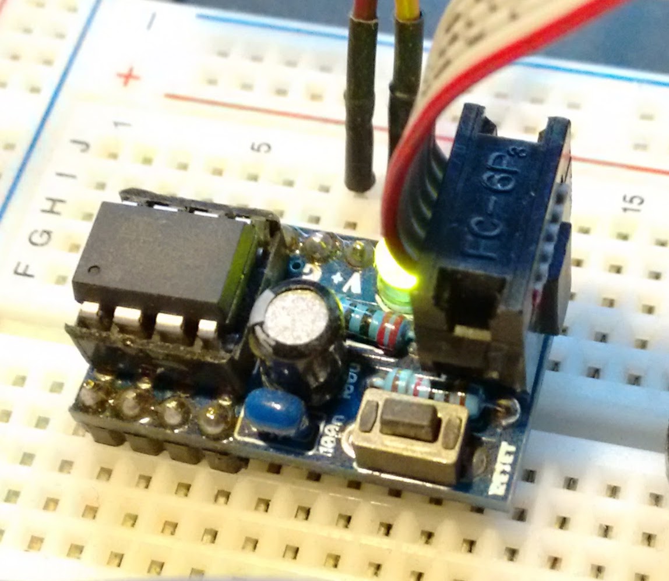
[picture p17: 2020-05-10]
TinyTOG_NEW_with_ATtiny25/docs/Attiny-ISP/attiny_Brenner_Anschluss.jpg

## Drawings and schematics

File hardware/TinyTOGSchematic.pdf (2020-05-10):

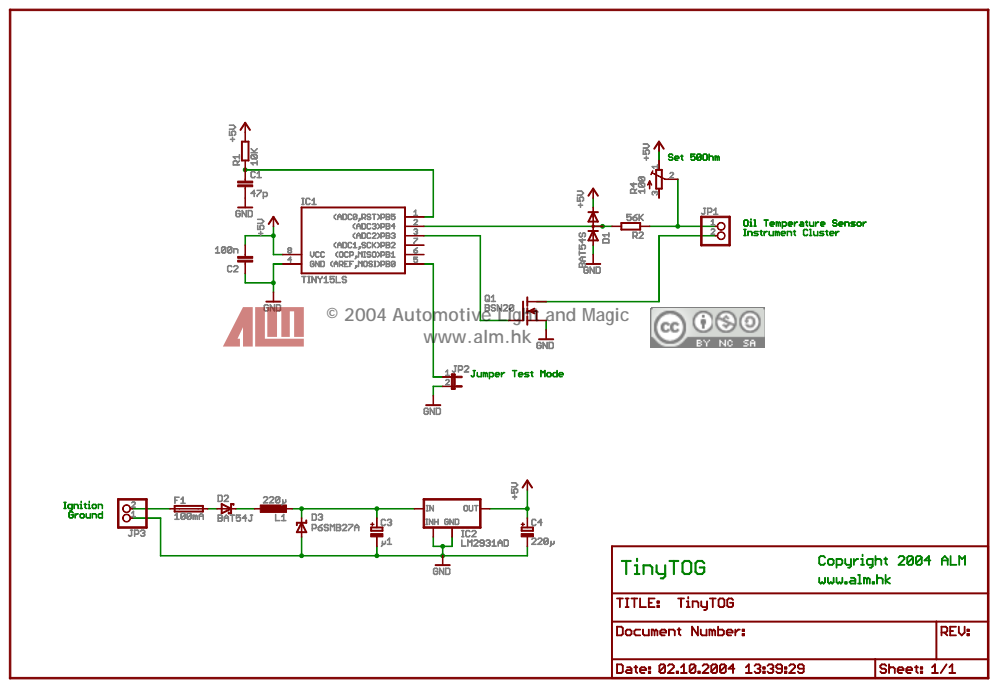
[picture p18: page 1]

© 2004 Automotive Light and Magic

www.alm.hk

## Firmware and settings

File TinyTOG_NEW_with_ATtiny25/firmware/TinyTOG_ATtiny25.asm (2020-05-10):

//==============================================================================
// File:		TinyTOG.asm
// Compiler:	AVR Studio 3.11 www.atmel.com
// Output Size:	-
// Created:    	Sat Aug 15 10:39:35 2004
// Copyright:	(C) 2004 ALM, Hong Kong
//
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
.include "tn25def.inc"

.def lowL = r4
.def lowH = r5

.def highL = r6
.def highH = r7

.def temp1 = r16
.def temp2 = r17

.def demodelay = r18
.def democnt = r19

.def waitcnt = r20
.def waitcntL = r21
.def waitcntH = r22

MAIN:

	; PB4 (pin2 in tiny15 mode) = ADC input from oil temperature sensor
	; PB3 (pin3 in tiny15 mode) = PWM output to instrument cluster
	; PB0 (pin5) = Jumper for demo mode (low=demo)
	
	; Prepare port
	ldi temp1, 0b00001000 
	out DDRB, temp1 ; all PBx as input except PB3
	ldi temp1, 0b00001111
	out PORTB, temp1 ; all PBx with pull up
	
	; Prepare ADC
	ldi temp1, 0b00100011
	out ADMUX, temp1
	ldi temp1, 0b11100000
	out ADCSRA, temp1
	
	; Calibrate 
	ldi temp1, low( CAL_BYTE<<1 )
	mov ZL, temp1
	ldi temp1, high( CAL_BYTE<<1 )
	mov ZH, temp1
	lpm
	out OSCCAL, r0
	
	; Jump to demo mode?
	sbis PINB, 0
	rjmp DEMO

MAIN_LOOP:
	rcall ADC_VALUE
	rcall LOAD_TOG_VALUES
	rcall OUT_VALUE
	rjmp MAIN_LOOP

OUT_VALUE:

	cbi PORTB, 3 ; first pulse, 20 ms

	ldi waitcntL, 160
	ldi waitcntH, 0
	rcall WAIT

	sbi PORTB, 3 ; break between pulses, duration from table

	mov waitcntL, lowL
	mov waitcntH, lowH
	rcall WAIT

	cbi PORTB, 3 ; second pulse, duration from table
	
	mov waitcntL, highL
	mov waitcntH, highH
	rcall WAIT

	sbi PORTB, 3 ; fixed break, at least 250 ms

	ldi waitcntL, 208
	ldi waitcntH, 7
	rcall WAIT

	ret

/*******************************************************************************
* Procedure: ADC_VALUE
* Reads ADC and delivers back an index on the loopup table in temp1
*******************************************************************************/

ADC_VALUE:
	in temp2, ADCH
ADC_41:		
	cpi temp2, 246 ; 217
	brlo ADC_60	
	ldi temp1, 0
	ret
ADC_60:
	cpi temp2, 235 ; 213
	brlo ADC_65
	ldi temp1, 1
	ret
ADC_65:
	cpi temp2, 229 ; 203
	brlo ADC_70
	ldi temp1, 2
	ret
ADC_70:
	cpi temp2, 222 ; 192
	brlo ADC_75
	ldi temp1, 3
	ret
ADC_75:
	cpi temp2, 216 ; 183
	brlo ADC_80
	ldi temp1, 4
	ret
ADC_80:
	cpi temp2, 210 ; 174
	brlo ADC_85
	ldi temp1, 5
	ret
ADC_85:
	cpi temp2, 204 ; 165
	brlo ADC_90
	ldi temp1, 6
	ret
ADC_90:
	cpi temp2, 196 ; 150
	brlo ADC_95
	ldi temp1, 7
	ret
ADC_95:
	cpi temp2, 189 ; 146
	brlo ADC_100
	ldi temp1, 8
	ret
ADC_100:
	cpi temp2, 182 ; 138
	brlo ADC_105
	ldi temp1, 9
	ret
ADC_105:
	cpi temp2, 175 ; 129
	brlo ADC_110
	ldi temp1, 10
	ret
ADC_110:
	cpi temp2, 166 ; 121
	brlo ADC_115
	ldi temp1, 11
	ret
ADC_115:
	cpi temp2, 161 ; 115
	brlo ADC_120
	ldi temp1, 12
	ret
ADC_120:
	cpi temp2, 155 ; 108
	brlo ADC_125
	ldi temp1, 13
	ret
ADC_125:
	cpi temp2, 146 ; 93
	brlo ADC_130
	ldi temp1, 14
	ret
ADC_130:
	cpi temp2, 125 ; 81
	brlo ADC_135
	ldi temp1, 15
	ret
ADC_135:
	cpi temp2, 118 ; 75
	brlo ADC_140
	ldi temp1, 16
	ret
ADC_140:
	cpi temp2, 112 ; 69
	brlo ADC_145
	ldi temp1, 17
	ret
ADC_145:
	cpi temp2, 104 ; 63
	brlo ADC_150
	ldi temp1, 18
	ret
ADC_150:
	cpi temp2, 96 ; 58
	brlo ADC_155
	ldi temp1, 19
	ret
ADC_155:
	cpi temp2, 90 ; 53
	brlo ADC_160
	ldi temp1, 20
	ret
ADC_160:
	cpi temp2, 83 ; 50
	brlo ADC_165
	ldi temp1, 21
	ret
ADC_165:
	cpi temp2, 82 ; 49
	brlo ADC_170
	ldi temp1, 22
	ret
ADC_170:
	ldi temp1, 81 ; 23
	ret

/*******************************************************************************
* Procedure: DEMO
* Shifts output from 41°C to 170°C and back.
*******************************************************************************/

DEMO:
	ldi temp1, 23
	rcall LOAD_TOG_VALUES
	ldi demodelay, 20

DEMO_LOOP:
	rcall OUT_VALUE
	dec demodelay
	brne DEMO_LOOP
	ldi democnt, 23
	
DEMO_OUTER_LOOP:
	mov temp1, democnt
	rcall LOAD_TOG_VALUES
	ldi demodelay, 225

DEMO_INNER_LOOP:
	rcall OUT_VALUE
	dec demodelay
	brne DEMO_INNER_LOOP
	dec democnt
	brne DEMO_OUTER_LOOP
	rjmp DEMO

/*******************************************************************************
* Procedure: DEMO
* Load wait states from lookup table
*******************************************************************************/

LOAD_TOG_VALUES:

	lsl temp1
	lsl temp1

	ldi temp2, low( TOG_LOOKUP_TABLE<<1 )
	mov ZL, temp2
	ldi temp2, high( TOG_LOOKUP_TABLE<<1 )
	mov ZH, temp2

	add ZL, temp1
	ldi temp1,0
	adc ZH, temp1
	 
	ldi temp1, 1
	ldi temp2, 0

	lpm
	mov lowL, r0
	add ZL, temp1
	adc ZH, temp2
	lpm
	mov lowH, r0
	add ZL, temp1
	adc ZH, temp2
	lpm
	mov highL, r0
	add ZL, temp1
	adc ZH, temp2
	lpm
	mov highH, r0

	ret

/*******************************************************************************
* Procedure: DEMO
* Just a few wait staites...
*******************************************************************************/

WAIT:
	subi waitcntL, 1
	sbci waitcntH, 0

WAIT_LOOP:
	ldi waitcnt, 47
	rcall WAITING
	subi waitcntL, 1
	sbci waitcntH, 0
	brne WAIT_LOOP
	ldi waitcnt, 45
	nop
	nop
	rcall WAITING
	ret

WAITING:
	nop
	dec waitcnt
	brne WAITING
	nop
	ret

TOG_LOOKUP_TABLE:
; temperature in °C
; delay between first and second pulse, duration of second pulse
.dw 188, 192	; 0.   41
.dw 210, 216	; 1.   60
.dw 216, 222	; 2.   65
.dw 224, 226	; 3.   70
.dw 228, 234	; 4.   75
.dw 234, 240	; 5.   80
.dw 242, 246	; 6.   85
.dw 248, 252	; 7.   90
.dw 254, 260	; 8.   95
.dw 260, 266	; 9.  100
.dw 266, 272	; 10. 105
.dw 272, 280	; 11. 110
.dw 280, 286	; 12. 115
.dw 286, 294	; 13. 120
.dw 294, 300	; 14. 125
.dw 300, 306	; 15. 130
.dw 306, 314	; 16. 135
.dw 314, 320	; 17. 140
.dw 320, 326	; 18. 145
.dw 328, 334	; 19. 150
.dw 334, 342	; 20. 155
.dw 342, 348	; 21. 160
.dw 348, 356	; 22. 165
.dw 356, 362	; 23. 170
.dw 368, 374	; 24. 175

CAL_BYTE:
;.dw 0b00110011 ; 51 ; 21.0 ms
.dw 0b00111100 ; 60 ;
;.dw 0b01010001 ; 81 ; 17.6 ms 

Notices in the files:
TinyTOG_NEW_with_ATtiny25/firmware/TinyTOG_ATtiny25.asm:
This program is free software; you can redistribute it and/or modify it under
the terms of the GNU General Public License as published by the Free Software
